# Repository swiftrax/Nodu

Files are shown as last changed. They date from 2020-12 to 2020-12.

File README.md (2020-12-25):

# Nodu
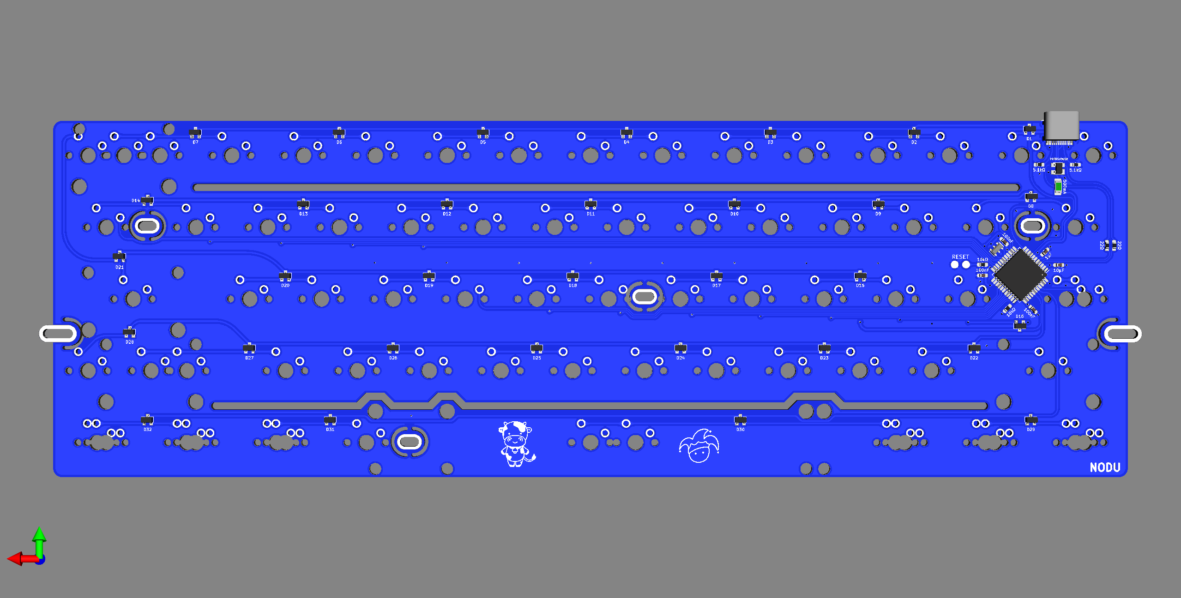
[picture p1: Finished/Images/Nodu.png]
3D Render

A 60% keyboard that fits most universal cases. PCB is based on Gondolindrim's Lasgweloth

## Supported layouts
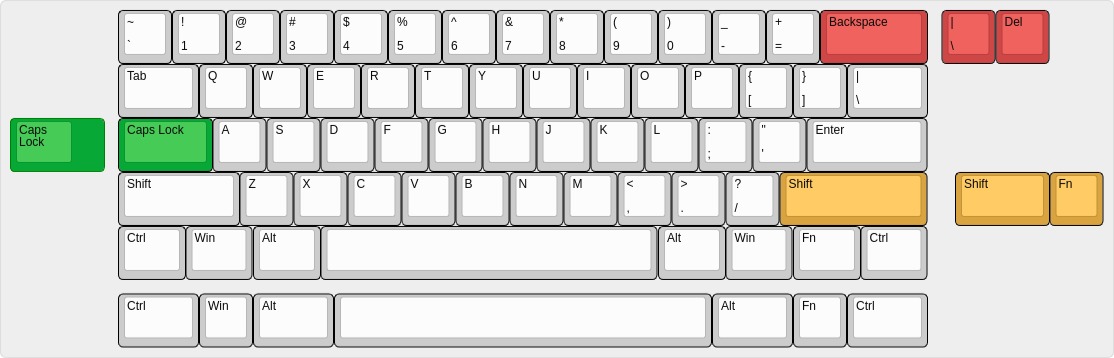
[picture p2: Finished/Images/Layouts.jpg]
Supported layouts of Nodu


## PCB Renders
**Top**
Top
**Bottom**
Bottom

## Bill of materials (BOM)
Amount is per PCB, multiply as needed.

| LCSC part # | Description | Value | Package  | Amount |
| --- | --- | ----- | --- | ---:|
| C14663 | Capacitor | 0.1uF | 0603 | 3 |
| C19702 | Capacitor | 10uF  | 0603 | 1 |
| C15849 | Capacitor | 1uF | 0603 | 1 |
| C68978 | Diode | | SOT-23-3 | 32 |
| C70076 | Fuse | | 1206 | 1 |
| C165948 | Connector | | SMD/THT  | 1 |
| C25804 | Resistor | 10K | 0603 | 2 |
| C23186 | Resistor | 5.1K  | 0603 | 2 |
| C23345 | Resistor | 22 | 0603 | 2 |
| C44854 | MCU | 32U4  | QFP-44 | 1 |
| C12333 | ESD chip | | SOT-143B | 1 |
| C341521 | Resonator | 16MHz | SMD | 1 |

## License

This repository is under the [CC0 1.0 Universal License](https://github.com/swiftrax/Nodu/blob/main/LICENSE). If you plan to sell these pcbs, make sure to read it.

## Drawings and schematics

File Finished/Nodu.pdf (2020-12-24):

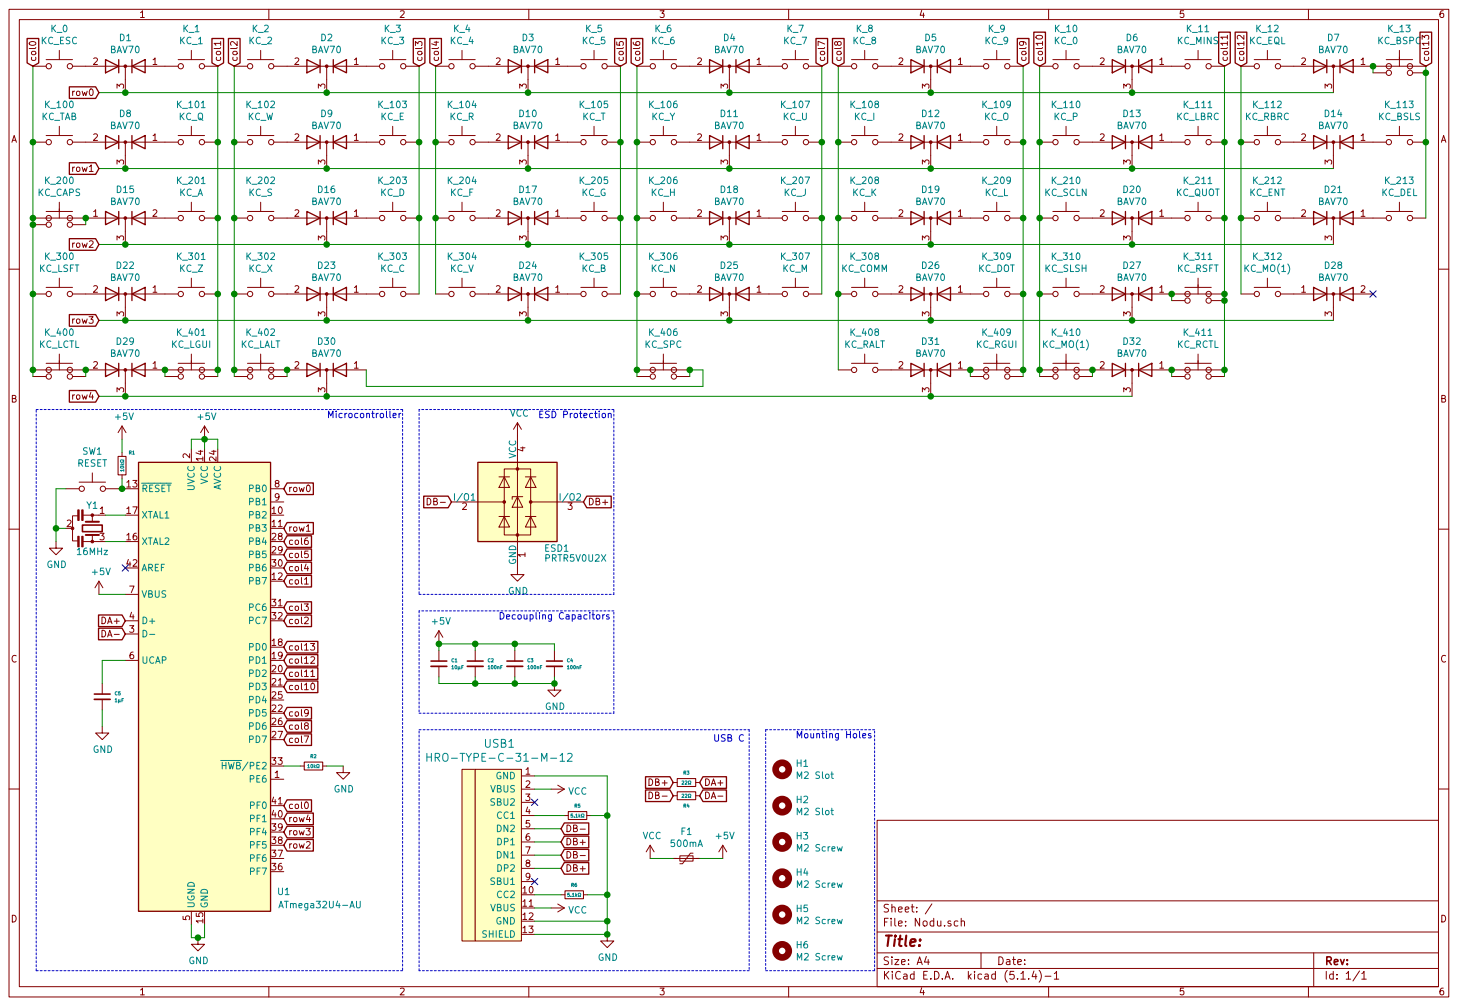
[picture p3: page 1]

K_211 KC_QUOT

K_305 KC_B | K_309 KC_DOT

ESD Protection Decoupling Capacitors

2 PD2 20 PD3 21 PD5 22 AVCC 24 PD4 25 PD6 26 PD7 27 PB4 28 PB5 29 D- 3 PB6 30 PC6 31 PC7 32 HWB/PE2 33 PF7 36 PF6 37 PF5 38 PF4 39 D+ 4 PF1 40 PF0 41 AREF 42 UGND

Id: 1/1 Title: File: Nodu.sch Sheet: /

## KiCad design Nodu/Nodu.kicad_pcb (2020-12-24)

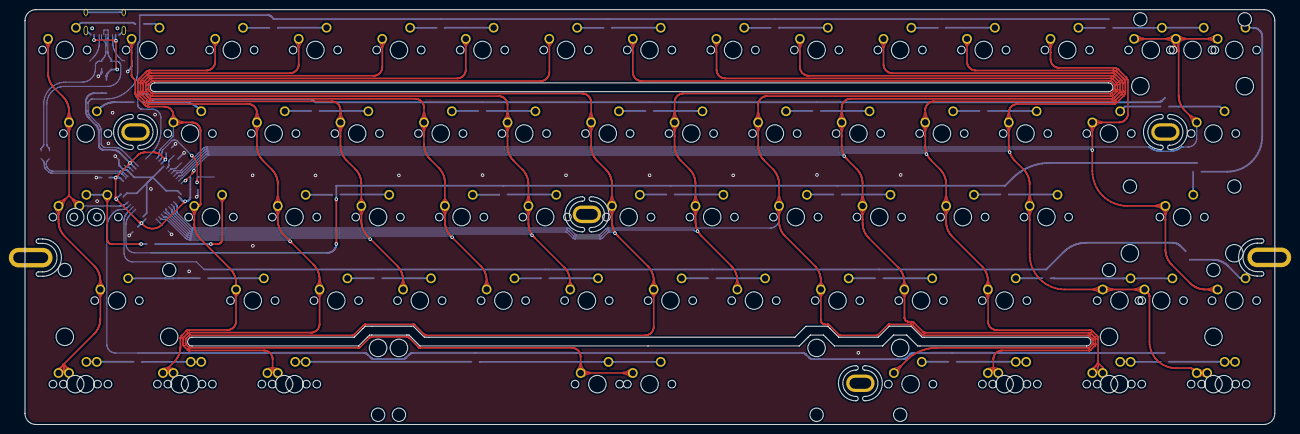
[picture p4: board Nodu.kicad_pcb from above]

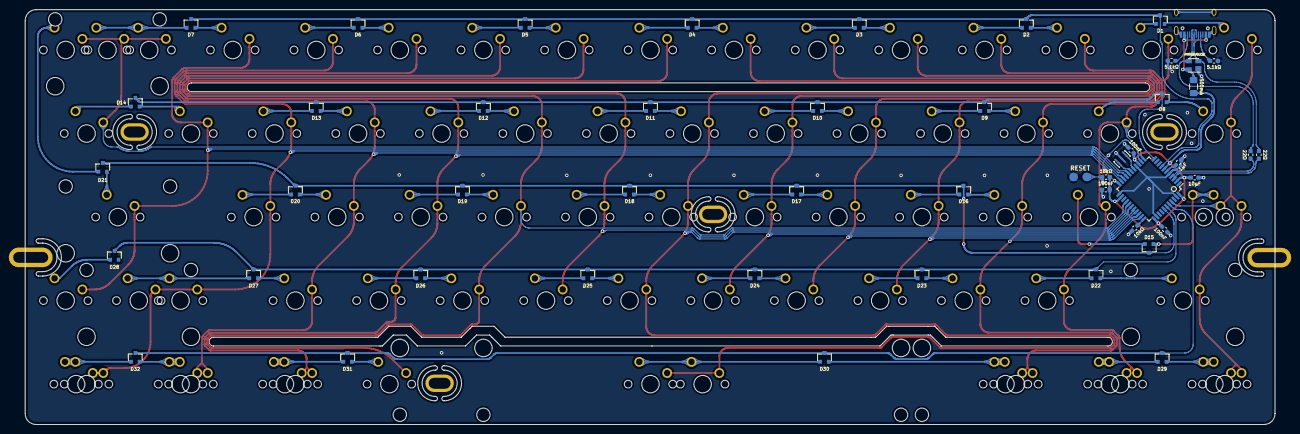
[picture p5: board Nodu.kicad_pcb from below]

Board: 2 copper layers, 285.0 x 94.6 mm, 128 parts (49 on the bottom side), 96 nets.

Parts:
C1: 10µF; C_0603_Annotated
C2, C3, C4: 100nF; C_0603_Annotated
C5: 1µF; C_0603_Annotated
D1, D2, D3, D4, D5, D6, D7, D8, D9, D10, D11, D12, D13, D14, D15, D16, D17, D18, D19, D20, D21, D22, D23, D24, D25, D26, D27, D28, D29, D30, D31, D32: BAV70; SOT-23_Annotated
ESD1: PRTR5V0U2X; SOT-143
F1: 500mA; Fuse_1206_Annotated
H1: M2 Slot; Flex_M2_Left
H2: M2 Slot; Flex_M2_Right
H3, H4, H5, H6: M2 Screw; Flex_M2_Hole
K_0: KC_ESC; MXOnly-1U-NoLED
K_1: KC_1; MXOnly-1U-NoLED
K_2: KC_2; MXOnly-1U-NoLED
K_3: KC_3; MXOnly-1U-NoLED
K_4: KC_4; MXOnly-1U-NoLED
K_5: KC_5; MXOnly-1U-NoLED
K_6: KC_6; MXOnly-1U-NoLED
K_7: KC_7; MXOnly-1U-NoLED
K_8: KC_8; MXOnly-1U-NoLED
K_9: KC_9; MXOnly-1U-NoLED
K_10: KC_0; MXOnly-1U-NoLED
K_11: KC_MINS; MXOnly-1U-NoLED
K_12: KC_EQL; MXOnly-1U-NoLED
K_13: KC_BSPC; MXOnly-2U-NoLED
K_013A1: KC_BSPC; MXOnly-1U-NoLED
K_100: KC_TAB; MXOnly-1.5U-NoLED
K_101: KC_Q; MXOnly-1U-NoLED
K_102: KC_W; MXOnly-1U-NoLED
K_103: KC_E; MXOnly-1U-NoLED
K_104: KC_R; MXOnly-1U-NoLED
K_105: KC_T; MXOnly-1U-NoLED
K_106: KC_Y; MXOnly-1U-NoLED
K_107: KC_U; MXOnly-1U-NoLED
K_108: KC_I; MXOnly-1U-NoLED
K_109: KC_O; MXOnly-1U-NoLED
K_110: KC_P; MXOnly-1U-NoLED
K_111: KC_LBRC; MXOnly-1U-NoLED
K_112: KC_RBRC; MXOnly-1U-NoLED
K_113: KC_BSLS; MXOnly-1.5U-NoLED
K_200: KC_CAPS; MXOnly-1.75U-NoLED
K_200A1: KC_CAPS; MXOnly-1.25U-NoLED
K_201: KC_A; MXOnly-1U-NoLED
K_202: KC_S; MXOnly-1U-NoLED
K_203: KC_D; MXOnly-1U-NoLED
K_204: KC_F; MXOnly-1U-NoLED
K_205: KC_G; MXOnly-1U-NoLED
K_206: KC_H; MXOnly-1U-NoLED
K_207: KC_J; MXOnly-1U-NoLED
K_208: KC_K; MXOnly-1U-NoLED
K_209: KC_L; MXOnly-1U-NoLED
K_210: KC_SCLN; MXOnly-1U-NoLED
K_211: KC_QUOT; MXOnly-1U-NoLED
K_212: KC_ENT; MXOnly-2.25U-NoLED
K_213: KC_DEL; MXOnly-1U-NoLED
K_300: KC_LSFT; MXOnly-2.25U-NoLED
K_301: KC_Z; MXOnly-1U-NoLED
K_302: KC_X; MXOnly-1U-NoLED
K_303: KC_C; MXOnly-1U-NoLED
K_304: KC_V; MXOnly-1U-NoLED
K_305: KC_B; MXOnly-1U-NoLED
K_306: KC_N; MXOnly-1U-NoLED
K_307: KC_M; MXOnly-1U-NoLED
K_308: KC_COMM; MXOnly-1U-NoLED
K_309: KC_DOT; MXOnly-1U-NoLED
K_310: KC_SLSH; MXOnly-1U-NoLED
K_311: KC_RSFT; MXOnly-2.75U-NoLED
K_311A1: KC_RSFT; MXOnly-1.75U-NoLED
K_312, K_410A1: KC_MO(1); MXOnly-1U-NoLED
K_400: KC_LCTL; MXOnly-1.25U-NoLED
K_400A1: KC_LCTL; MXOnly-1.5U-NoLED
K_401: KC_LGUI; MXOnly-1.25U-NoLED
K_401A1: KC_LGUI; MXOnly-1U-NoLED
K_402: KC_LALT; MXOnly-1.25U-NoLED
K_402A1: KC_LALT; MXOnly-1.5U-NoLED
K_406: KC_SPC; MXOnly-6.25U-ReversedStabilizers-NoLED
K_406A1: KC_SPC; MXOnly-7U-ReversedStabilizers-NoLED
K_408: KC_RALT; MXOnly-1.25U-NoLED
K_409: KC_RGUI; MXOnly-1.25U-NoLED
K_409A1: KC_RALT; MXOnly-1.5U-NoLED
K_410: KC_MO(1); MXOnly-1.25U-NoLED
K_411: KC_RCTL; MXOnly-1.25U-NoLED
K_411A1: KC_RCTL; MXOnly-1.5U-NoLED
R1, R2: 10kΩ; R_0603_Annotated
R3, R4: 22Ω; R_0603_Annotated
R5, R6: 5.1kΩ; R_0603_Annotated
SW1: RESET; RESET_PADS
U1: ATmega32U4-AU; ATMEGA32U4_Annotated
USB1: HRO-TYPE-C-31-M-12
Y1: 16MHz; Resonator_3Pin_Annotated

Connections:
+5V: C1.1, C2.1, C3.1, C4.1, F1.1, R1.1, U1.2, U1.7, U1.14, U1.24, U1.34, U1.44
DA+: R3.1, U1.4
DA-: R4.1, U1.3
DB+: ESD1.3, R3.2, USB1.6, USB1.8
DB-: ESD1.2, R4.2, USB1.5, USB1.7
GND: C1.2, C2.2, C3.2, C4.2, C5.2, ESD1.1, R2.1, R5.1, R6.1, SW1.1, U1.5, U1.15, U1.23, U1.35, U1.43, USB1.1, USB1.12, USB1.13, Y1.2
unnamed: C5.1, U1.6
unnamed: D1.1, K_1.2
unnamed: D1.2, K_0.2
unnamed: D2.1, K_3.2
unnamed: D2.2, K_2.2
unnamed: D3.1, K_5.2
unnamed: D3.2, K_4.2
unnamed: D4.1, K_7.2
unnamed: D4.2, K_6.2
unnamed: D5.1, K_9.2
unnamed: D5.2, K_8.2
unnamed: D6.1, K_11.2
unnamed: D6.2, K_10.2
unnamed: D7.1, K_13.2, K_013A1.2
unnamed: D7.2, K_12.2
unnamed: D8.1, K_101.2
unnamed: D8.2, K_100.2
unnamed: D9.1, K_103.2
unnamed: D9.2, K_102.2
unnamed: D10.1, K_105.2
unnamed: D10.2, K_104.2
unnamed: D11.1, K_107.2
unnamed: D11.2, K_106.2
unnamed: D12.1, K_109.2
unnamed: D12.2, K_108.2
unnamed: D13.1, K_111.2
unnamed: D13.2, K_110.2
unnamed: D14.1, K_113.2
unnamed: D14.2, K_112.2
unnamed: D15.1, K_200.2, K_200A1.2
unnamed: D15.2, K_201.2
unnamed: D16.1, K_203.2
unnamed: D16.2, K_202.2
unnamed: D17.1, K_205.2
unnamed: D17.2, K_204.2
unnamed: D18.1, K_207.2
unnamed: D18.2, K_206.2
unnamed: D19.1, K_209.2
unnamed: D19.2, K_208.2
unnamed: D20.1, K_211.2
unnamed: D20.2, K_210.2
unnamed: D21.1, K_213.2
unnamed: D21.2, K_212.2
unnamed: D22.1, K_301.2
unnamed: D22.2, K_300.2
unnamed: D23.1, K_303.2
unnamed: D23.2, K_302.2
unnamed: D24.1, K_305.2
unnamed: D24.2, K_304.2
unnamed: D25.1, K_307.2
unnamed: D25.2, K_306.2
unnamed: D26.1, K_309.2
unnamed: D26.2, K_308.2
unnamed: D27.1, K_311.2, K_311A1.2
unnamed: D27.2, K_310.2
unnamed: D28.1, K_312.2
unnamed: D29.1, K_401.2, K_401A1.2
unnamed: D29.2, K_400.2, K_400A1.2
unnamed: D30.1, K_406.2, K_406A1.2
unnamed: D30.2, K_402.2, K_402A1.2
unnamed: D31.1, K_409.2, K_409A1.2
unnamed: D31.2, K_408.2
unnamed: D32.1, K_411.2, K_411A1.2
unnamed: D32.2, K_410.2, K_410A1.2
unnamed: R1.2, SW1.2, U1.13
unnamed: R2.2, U1.33
unnamed: R5.2, USB1.4
unnamed: R6.2, USB1.10
unnamed: U1.16, Y1.3
unnamed: U1.17, Y1.1
VCC: ESD1.4, F1.2, USB1.2, USB1.11
col0: K_0.1, K_100.1, K_200.1, K_200A1.1, K_300.1, K_400.1, K_400A1.1, U1.41
col1: K_1.1, K_101.1, K_201.1, K_301.1, K_401.1, K_401A1.1, U1.12
col2: K_2.1, K_102.1, K_202.1, K_302.1, K_402.1, K_402A1.1, U1.32
col3: K_3.1, K_103.1, K_203.1, K_303.1, U1.31
col4: K_4.1, K_104.1, K_204.1, K_304.1, U1.30
col5: K_5.1, K_105.1, K_205.1, K_305.1, U1.29
col6: K_6.1, K_106.1, K_206.1, K_306.1, K_406.1, K_406A1.1, U1.28
col7: K_7.1, K_107.1, K_207.1, K_307.1, U1.27
col8: K_8.1, K_108.1, K_208.1, K_308.1, K_408.1, U1.26
col9: K_9.1, K_109.1, K_209.1, K_309.1, K_409.1, K_409A1.1, U1.22
col10: K_10.1, K_110.1, K_210.1, K_310.1, K_410.1, K_410A1.1, U1.21
col11: K_11.1, K_111.1, K_211.1, K_311.1, K_311A1.1, K_411.1, K_411A1.1, U1.20
col12: K_12.1, K_112.1, K_212.1, K_312.1, U1.19
col13: K_13.1, K_013A1.1, K_113.1, K_213.1, U1.18
row0: D1.3, D2.3, D3.3, D4.3, D5.3, D6.3, D7.3, U1.8
row1: D8.3, D9.3, D10.3, D11.3, D12.3, D13.3, D14.3, U1.11
row2: D15.3, D16.3, D17.3, D18.3, D19.3, D20.3, D21.3, U1.38
row3: D22.3, D23.3, D24.3, D25.3, D26.3, D27.3, D28.3, U1.39
row4: D29.3, D30.3, D31.3, D32.3, U1.40

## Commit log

2020-12-12 Add flex cutouts
    [Flex60.kicad_pcb, Flex60.sch, Flex60_Edgecuts.dxf]
2020-12-12 Layout of switches
    [Flex60.kicad_pcb, Flex60.sch]
2020-12-12 Layout Diodes + add flex cuts
    [Flex60.kicad_pcb, Flex60.sch]
2020-12-12 Fix Edgecuts
    [Flex60.kicad_pcb]
2020-12-12 Add MCU + USB circuits
    [Flex60.sch]
2020-12-12 Add Footprints + 3D models
    [Flex60.kicad_pcb, Flex60.sch]
2020-12-13 MCU placement
    [Flex60.kicad_pcb, Flex60.sch]
2020-12-13 Route Cols
    [Flex60.kicad_pcb]
2020-12-13 Change reset pads
    [Flex60.kicad_pcb]
2020-12-13 Route Matrix
    [Flex60.kicad_pcb, Flex60.sch]
2020-12-13 Add teardrops
    [Flex60.kicad_pcb]
2020-12-14 Fix routing
    [Flex60.kicad_pcb]
2020-12-14 Add Plate + Gerbers
    [Flex60-B_Cu.gbr, Flex60-B_Mask.gbr, Flex60-B_SilkS.gbr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]
2020-12-14 Add Art + generate new gerbers
    [Flex60-B_Cu.gbr, Flex60-B_Mask.gbr, Flex60-B_SilkS.gbr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]
2020-12-15 Add stuff for rendering
    [Flex60.kicad_pcb]
2020-12-24 Add gerbers
    [Flex60_Edgecuts.dxf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]
2020-12-24 Add finished files
    [Flex60_Plate_EdgeCuts.dxf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]
